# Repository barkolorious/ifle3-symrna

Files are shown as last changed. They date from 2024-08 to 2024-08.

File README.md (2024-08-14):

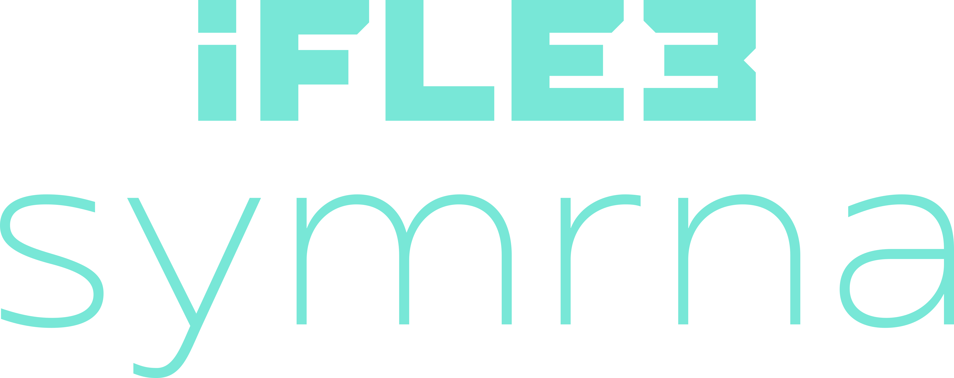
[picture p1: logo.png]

A computer based on Ben Eater's 6502 series.

The IC's were bought from Mouser and the PCB was manufactured by JLCPCB.
Here's the list of the IC's I used:
- **W65C02S6TPG-14**
  - MPU 8-bit Microprocessor
- **AS6C62256-55PCN**
  - SRAM 256K, 2.7-5.5V, 55ns 32K x 8 Asynch SRAM
- **AT28C256-15PU**
  - EEPROM 256K 32K x 8 150 ns 4.5V-5.5V
- **W65C22S6TPG-14**
  - Controller Interface IC Versatile Interface Adapter
- **W65C51N6TPG-14**
  - Specialised Asynch Communication Interface Adapter
- **MAX232EIN**
  - RS232 Line Driver/Receiver

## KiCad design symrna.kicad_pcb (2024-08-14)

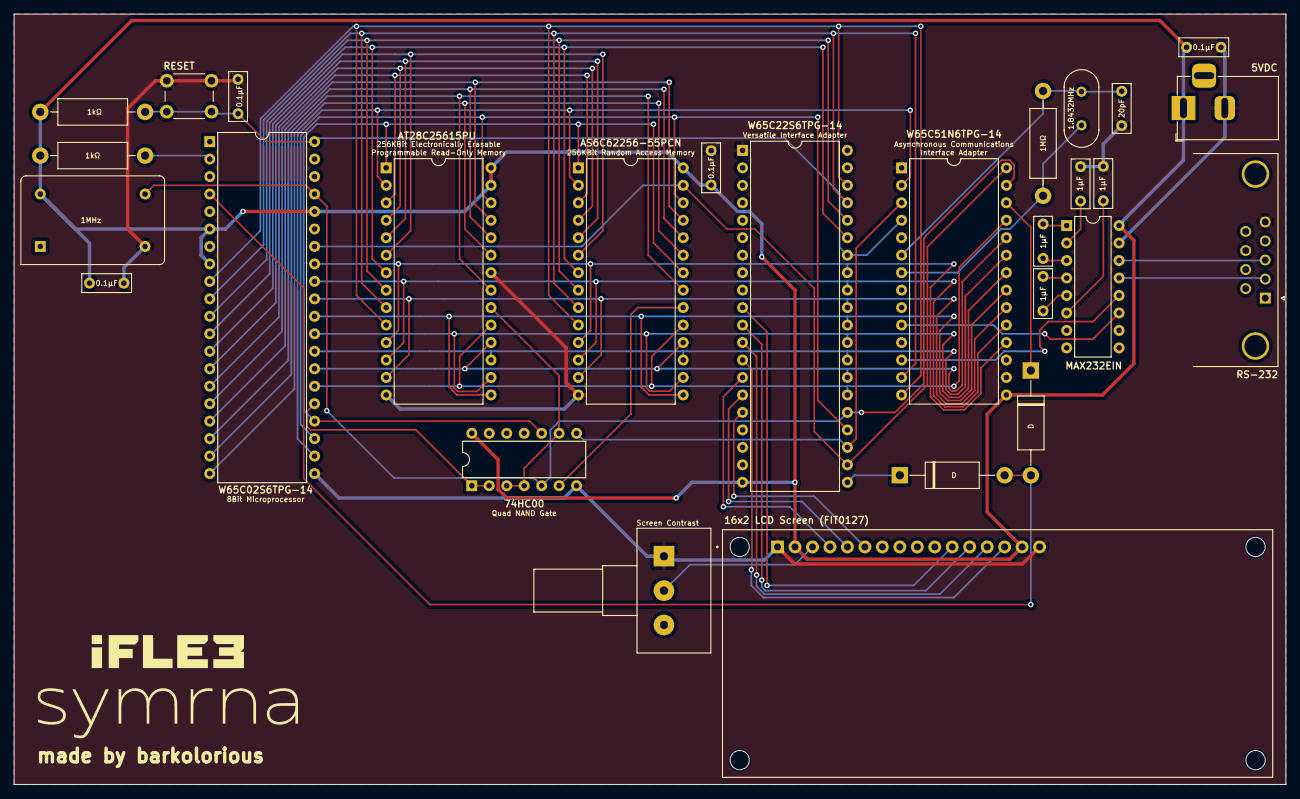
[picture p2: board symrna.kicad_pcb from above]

Board: 2 copper layers, 184.9 x 112.0 mm, 28 parts (0 on the bottom side), 56 nets.

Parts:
C1: 20pF; C_Disc_D7.0mm_W2.5mm_P5.00mm
C2, C3, C4, C5: 1µF; C_Disc_D7.0mm_W2.5mm_P5.00mm
C6, C7, C8, C9: 0.1µF; C_Disc_D7.0mm_W2.5mm_P5.00mm
D25, D26: D; D_DO-15_P15.24mm_Horizontal
J1: DE9_Plug; DSUB-9_Female_Horizontal_P2.77x2.84mm_EdgePinOffset7.70mm_H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
J2: Jack-DC; BarrelJack_Horizontal
R25: 1MΩ; R_Axial_DIN0411_L9.9mm_D3.6mm_P15.24mm_Horizontal
R26, R27: 1kΩ; R_Axial_DIN0411_L9.9mm_D3.6mm_P15.24mm_Horizontal
RV1: R_Potentiometer; Potentiometer_Alps_RK163_Single_Horizontal
SW1: SW_Push; SW_PUSH_6mm_H7.3mm
U1: 28C256; DIP-28_W15.24mm
U2: HM62256BLP; DIP-28_W15.24mm
U3: MAX232; DIP-16_W7.62mm
U4: 74HC00; DIP-14_W7.62mm
U5: W65C02SxP; DIP-40_W15.24mm
U6: W65C22NxP; DIP-40_W15.24mm
U7: W65C51NxP; DIP-28_W15.24mm
U8: LCD-16X2; MODULE_LCD-16X2
X1: 1MHz; Oscillator_DIP-14
Y1: 1.8432MHz; Crystal_HC49-U_Vertical

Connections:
+5V: C7.1, C8.1, C9.1, J2.1, R26.1, R27.1, U1.27 (~WE), U1.28 (VCC), U2.28 (VCC), U3.16 (VCC), U4.14 (VCC), U5.6 (~NMI), U5.8 (VDD), U5.36 (BE), U6.20 (VCC), U7.15 (VCC), U8.2 (VDD), U8.15 (A), X1.14 (Vcc)
/a0: U1.10 (A0), U2.10 (A0), U5.9 (A0), U6.38 (RS0), U7.14 (RS1)
/a1: U1.9 (A1), U2.9 (A1), U5.10 (A1), U6.37 (RS1), U7.13 (RS0)
/a2: U1.8 (A2), U2.8 (A2), U5.11 (A2), U6.36 (RS2)
/a3: U1.7 (A3), U2.7 (A3), U5.12 (A3), U6.35 (RS3)
/a4: U1.6 (A4), U2.6 (A4), U5.13 (A4)
/a5: U1.5 (A5), U2.5 (A5), U5.14 (A5)
/a6: U1.4 (A6), U2.4 (A6), U5.15 (A6)
/a7: U1.3 (A7), U2.3 (A7), U5.16 (A7)
/a8: U1.25 (A8), U2.25 (A8), U5.17 (A8)
/a9: U1.24 (A9), U2.24 (A9), U5.18 (A9)
/a10: U1.21 (A10), U2.21 (A10), U5.19 (A10)
/a11: U1.23 (A11), U2.23 (A11), U5.20 (A11)
/a12: U1.2 (A12), U2.2 (A12), U5.22 (A12), U7.2 (CS1)
/a13: U1.26 (A13), U2.26 (A13), U5.23 (A13), U6.24 (CS1)
/a14: U1.1 (A14), U2.1 (A14), U2.22 (~OE), U4.10, U5.24 (A14)
/a15: U4.1, U4.2, U5.25 (A15)
/d0: U1.11 (D0), U2.11 (Q0), U5.33 (D0), U6.33 (D0), U7.18 (D0)
/d1: U1.12 (D1), U2.12 (Q1), U5.32 (D1), U6.32 (D1), U7.19 (D1)
/d2: U1.13 (D2), U2.13 (Q2), U5.31 (D2), U6.31 (D2), U7.20 (D2)
/d3: U1.15 (D3), U2.15 (Q3), U5.30 (D3), U6.30 (D3), U7.21 (D3)
/d4: U1.16 (D4), U2.16 (Q4), U5.29 (D4), U6.29 (D4), U7.22 (D4)
/d5: U1.17 (D5), U2.17 (Q5), U5.28 (D5), U6.28 (D5), U7.23 (D5)
/d6: U1.18 (D6), U2.18 (Q6), U5.27 (D6), U6.27 (D6), U7.24 (D6)
/d7: U1.19 (D7), U2.19 (Q7), U5.26 (D7), U6.26 (D7), U7.25 (D7)
GND: C1.2, C4.2, C5.2, C6.2, C7.2, C8.2, C9.2, J1.5, J2.2, RV1.1, SW1.1, U1.14 (GND), U1.22 (~OE), U2.14 (GND), U3.15 (GND), U4.7 (GND), U5.21 (VSS), U6.1 (VSS), U7.1 (VSS), U8.1 (VSS), U8.16 (K), X1.7 (GND)
unnamed: D25.2 (A), D26.2 (A), U5.4 (~IRQ)
unnamed: D25.1 (K), U6.21 (~IRQ)
unnamed: D26.1 (K), U7.26 (~IRQ)
unnamed: U1.20 (~CS), U4.3, U4.4, U4.9
unnamed: U2.20 (~CS), U4.6
unnamed: U2.27 (~WE), U5.34 (R/~W), U6.22 (R/~W), U7.28 (R/~W)
unnamed: C2.1, U3.1 (C1+)
unnamed: C2.2, U3.3 (C1-)
unnamed: C3.1, U3.4 (C2+)
unnamed: C3.2, U3.5 (C2-)
unnamed: J1.2, U3.13 (R1IN)
unnamed: U3.12 (R1OUT), U7.12 (RxD)
unnamed: U3.11 (T1IN), U7.10 (TxD)
unnamed: J1.3, U3.14 (T1OUT)
unnamed: C4.1, U3.2 (VS+)
unnamed: C5.1, U3.6 (VS-)
unnamed: R26.2, U5.2 (RDY)
unnamed: C6.1, R27.2, SW1.2, U5.40 (~RES), U6.34 (~RES), U7.4 (~RES)
unnamed: U4.5, U5.37 (ϕ0), U6.25 (ϕ2), U7.27 (ϕ2), X1.8 (OUT)
unnamed: U6.10 (PB0), U8.11 (DB4)
unnamed: U6.11 (PB1), U8.12 (DB5)
unnamed: U6.12 (PB2), U8.13 (DB6)
unnamed: U6.13 (PB3), U8.14 (DB7)
unnamed: U6.14 (PB4), U8.4 (RS)
unnamed: U6.15 (PB5), U8.5 (R/W)
unnamed: U6.16 (PB6), U8.6 (E)
unnamed: U4.8, U6.23 (~CS2), U7.3 (~CS2)
unnamed: C1.1, R25.1, U7.6 (XTAL1), Y1.2
unnamed: R25.2, U7.7 (XTAL2), Y1.1
unnamed: RV1.2, U8.3 (VO)
